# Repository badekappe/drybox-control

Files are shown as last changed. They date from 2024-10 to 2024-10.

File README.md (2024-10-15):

DryBox dryController
===

## Version 0.49.1

## Requirements
- Arduino IDE 1.8.2 or higher
- NewliquidCrystal (I2C)
- Adafruit SHT31 Library
- Adafruit BusIO (dependency of SHT31 library)

- 3D printing files and other parts list: https://www.printables.com/de/model/724722-filament-dry-box-heated-ventilated-arduino-control

## Changes with original
This is a detached fork from [werner_rh](https://github.com/werner-rh/drybox-control), in which I made the following changes:
- Replaced the DHT11 with SHT31. See also [this folder](./DHT31/)

## Description
Controller for an active heated and ventilated Filament DryBox. The Dryer contains a PTC Heater and a Fan for fresh dry air.

With one Heater, the box may barely reaches 55 degree. As max i reached 57 degree. I recommend not to go over 52-53 degree. If you need higher temperatures,
install a second heater. The MosFet switch will manage this. But you also need a stronger power supply (12V, 8-10A). A simple improvement
is insulating the walls inside. I used a car sun protect shield, with reflection and insulating. This improves the performance of
the box sigifignant. The warm up is much faster and also eaysier to to reach 55 degrees.

## Recommended drying temperatures
- PLA, PLA+                : 40-45 degree
- ABS, ABS+,  PETG         : 45-50 degree
- PVA,PVB, ASA, TPU, PMMA  : 50-55 degree

## Schematics
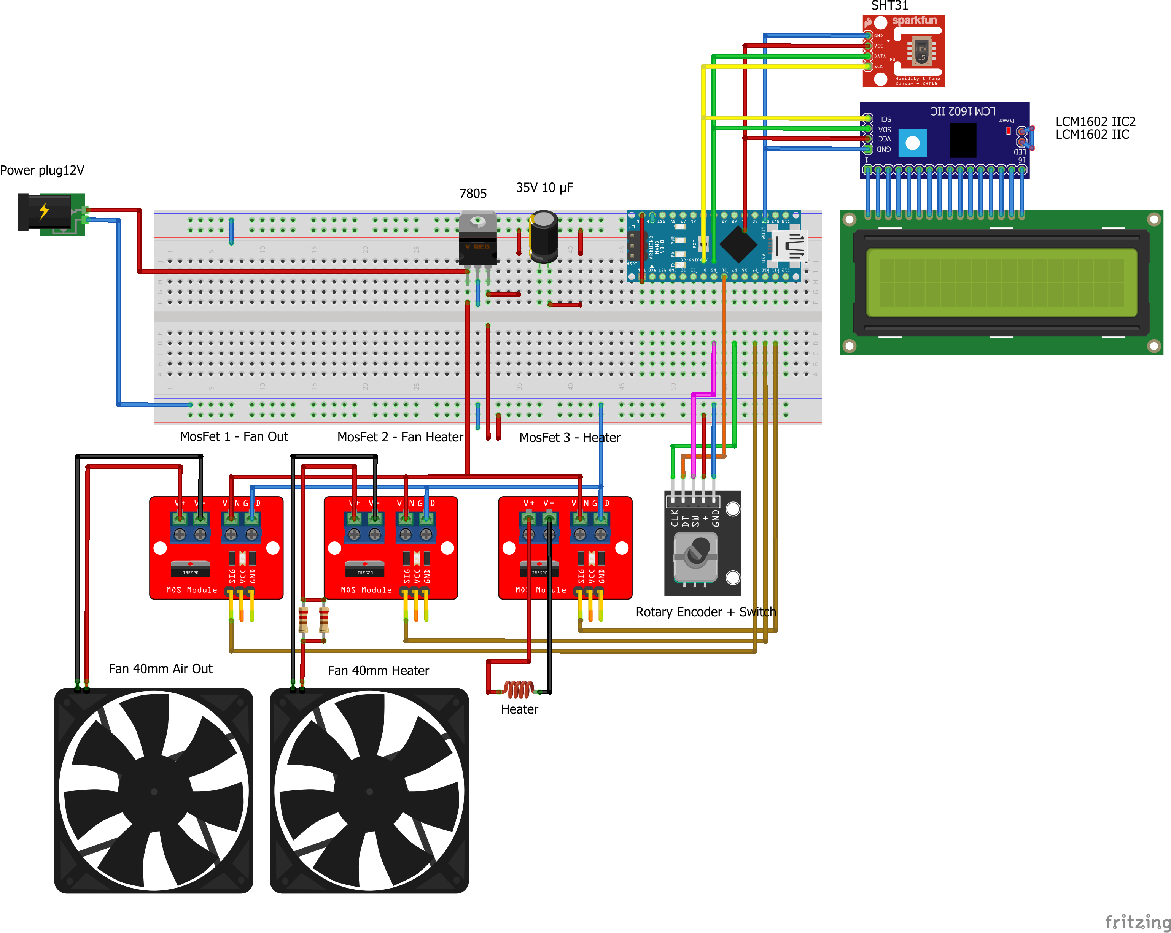
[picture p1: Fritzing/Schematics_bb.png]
On a breadboard


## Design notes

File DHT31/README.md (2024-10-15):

# DHT31
In this folder you'll find the files to print a mount for the DHT31 on a breakout board. You can glue or screw it in place, whichever you prefer.  
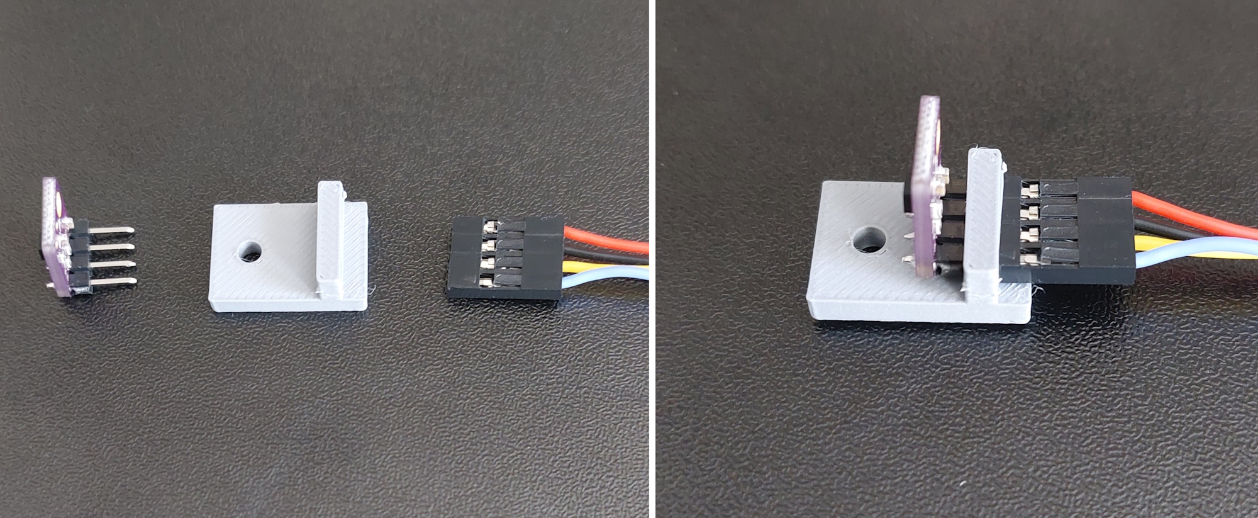
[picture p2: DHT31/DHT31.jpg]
mounting DHT31


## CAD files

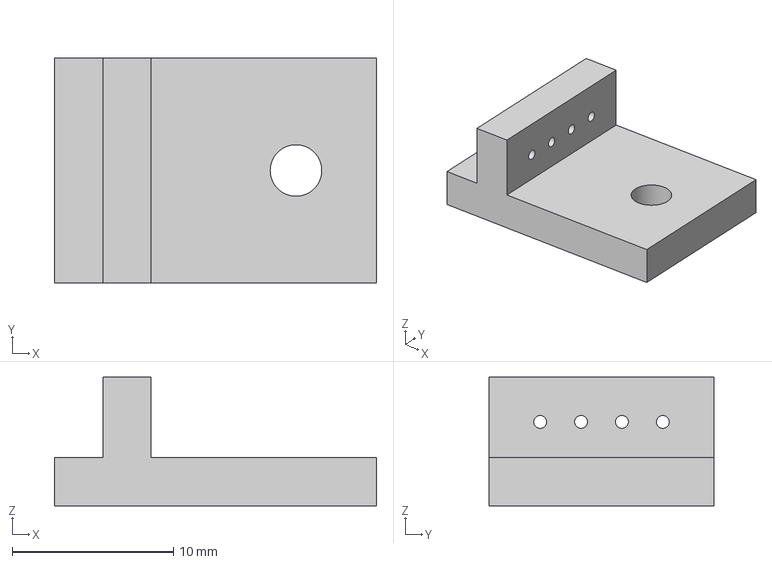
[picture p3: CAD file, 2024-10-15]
DHT31/DHT31-Mount.3mf
20.0 x 14.0 x 8.00 mm

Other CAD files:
DHT31/DHT31-Mount.stl

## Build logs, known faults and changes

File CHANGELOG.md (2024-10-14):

# Changelog
All notable changes for this project will be documented in this file

## [0.49.1] - 2024-10-14
### Changed
- Detached from original
- Replaced DHT11 with SHT31

## [0.49] - 2024-06-18
### Added
- Handling sensor error. If sensor fails during drying cycle, then drying process will be stopped and error message appear on the screen.
  
## [0.48] - 2024-05-08
### changed
- Refactoring Heating data. All values for heating power and heater fan speed are handled in an own class 
### Added
- Turbo mode for faster heating up in the lower ranges
- values for ventialtion time and final ventilation time
- replaced fix define for air exchange intervall with value in HeatingData

## [0.47] - 2024-05-05
### changed
- bugfix in function dryController(). Heater now is shut down after ventilation.
- bugfix in rampUpTable. Range over 50 degrees wasn't regarded and so powered to low.
### Added
- additional range over over 45 and 50 degrees. Now there are 6 ranges.
- display showing state of heater, heaterfan and ventilation during drying.
- refactored initializing power values for each tempeture range.
- adjust current values for low Hysteresis

## [0.46]
### Added
- last final ventilation after dry process is finished

## [0.45]
### Added
- first final version

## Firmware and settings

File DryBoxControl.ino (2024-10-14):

/***
 * Project: DryBox Control
 * File   : DryBoxControl.ino
 * Author : Werner Riemann 
 * Created: 18.10.2023
 * Board: Arduino Nano
 * 
 * Description: Controller for an active (heated) Filament DryBox.
 *              The Dryer contains a PTC Heater and a Fan for fresh dry air.
 *
 * Recommended drying temperatures:
 *    PLA, PLA+                : 40-45 degree
 *    ABS, ABS+,  PETG         : 45-50 degree
 *    PVA,PVB, ASA, TPU, PMMA  : 50-55 degree
 *
 *   Note: with one Heater, the box may barely reaches 55 degree. As max i reached 57 degree.
 *         I recommend not to go over 52-53 degree. If you need higher temperatures,
 *         install a second heater. The MosFet switch will manage this. But you
 *         also need a stronger power supply (12V, 8-10A).
 * 
 * Pins:
 * 
 * A4,A5  - I2C Display control and SHT31 (A4 - SDA, A5 - SCL)
 * 
 * 

 * D2     - not used
 * D1     - not used
 * D3     - not used
 * D4     - not used
 *
 * D5     - Rotary Encoder Switch
 * D6     - Rotary Encoder DT_pin                 Note: some encoder are different and you may have to change DT and CLK Pin.
 * D7     - Rotary Encoder CLK_pin                      Clockwise spin should increase all values.
 * D9     - Analog out PWM Fan Air exchange
 * D10    - Analog out PWM Fan Heating
 * D11    - Analog out PWM Heating
 * D12    - 
 * D13    - Digital out LEDPIN 13 (interne LED)
 * 
 *
 * --- Menu and functions ---
 * Main select: Temperature, Time, Start, Save, Version, Test functions (press Rotary to choose)
 * Temperature: change value by rotate, press to Rotary to exit
 * Time       : choose hour, minutes or Ret to exit. Press Rotary to enter value to change. Press Rotary again to exit value change.
 * Start      : press Rotary to start drying. Press Rotary during drying to pause or exit drying
 * Save       : press Rotary to save current setting for temperature and time to eeprom
 * Version    : shows the current version, press Rotary again to return to main
 * Test       : provides 3 functions for Heater, Heater Fan, Air Fan for Fresh air supply and exit Test.
 *              On exit Test menu, all values are set to zero and stops all modules.
 *
 *              This is useful to check all modules separately after assembling modules. Keep in mind to don't power
 *              up the heater without the fan for a longer time.
 */

#include <SPI.h>
#include <Wire.h>
#include <EEPROM.h>
#include <Arduino.h>
#include "Adafruit_SHT31.h"
#include "DryBoxControl.h"
#include "WRKeyStateDef.h"
#include "DryBoxDisplay.h"
#include "HeatingData.h"

volatile uint8_t B100HzToggle = 0;  // 100 Hertz Signal
uint8_t ui10MilliSekCount = 0;

int encoder_value = 500;
int last_encoder_value  = 500;
int EncSwitch = 5;
int DT_pin = 6;   //swap lines to change direction on the encoder
int CLK_pin = 7;  //swap lines to change direction on the encoder
int DT_pinstate;
int last_DT_pinstate;

int AirFanSpeed = 100;    // Extract Fan Speed in Percent
int HeatFanSpeed = 50;    // HeatFan Speed in Percent
int HeatingPower = 25;    // Heating Power in Percent

int testAirFanSpeed = 0;    // Extract Fan Speed in Percent for testing mode
int testHeatFanSpeed =0;    // HeatFan Speed in Percent for testing mode
int testHeatingPower =0;    // Heating Power in Percent for testing mode

// default values at startup, if nothing is stored in the eeprom
int DryTemperature = 35;    // Destination Dry Temperature in degree celsius
int DryTime_Hours = 1;      
int DryTime_Minutes = 30;
int curDryTime_Hours = 1;
int curDryTime_Minutes = 30;

//-- adjustable seetings for drying process, stored in HeatingData class
HeatingData heatingData;    // see HeatingData class


//-- State var for rotary encoder weitch  ----
uint8_t encoderBUTTON_State=0;

//-- Remember State on for Heater, Heater Fan and Ventilation
boolean StateHeaterOn = false;
boolean StateHeaterFanOn = false;
boolean StateVentilationOn = false;
boolean turboMode = false;

DryBoxDisplay display;
Adafruit_SHT31 sht31 = Adafruit_SHT31();


/***
 * Saves the current settings for temperature, drying hours and minutes
 */
void SaveSettings() {
  EEPROM.write(0, (uint8_t) 17);
  EEPROM.write(1, (uint8_t) DryTemperature);
  EEPROM.write(2, (uint8_t) DryTime_Hours);
  EEPROM.write(3, (uint8_t) DryTime_Minutes);
}


/***
 * Reads the last saved settings for temperature, drying hours and minutes
 */
void ReadSettings() {
  uint8_t isInit = EEPROM.read(0);

  if(isInit == 17) {
    DryTemperature = EEPROM.read(1);
    DryTime_Hours = EEPROM.read(2);
    DryTime_Minutes = EEPROM.read(3);
  }
}


// Interrupt is called once a millisecond, 
SIGNAL(TIMER0_COMPA_vect) 
{
  unsigned long currentMillis = millis();
  ui10MilliSekCount ++;

  if(ui10MilliSekCount >= 10 ) {
    ui10MilliSekCount = 0;
    B100HzToggle ^= 1;
  }

  ReadEncoder();  
}

void setup() {
  sht31.begin(0x44);
  
  // setup Rotary encoder
  pinMode (DT_pin, INPUT);
  pinMode (CLK_pin, INPUT);
  digitalWrite(DT_pin, HIGH);
  digitalWrite(CLK_pin, HIGH);

  // setup Heating and air 
  pinMode(FANAIR_PIN, OUTPUT);  
  analogWrite(FANAIR_PIN, 0);            // PWM Extrcat Fan off
  pinMode(FANHEATING_PIN, OUTPUT);  
  analogWrite(FANHEATING_PIN, 0);        // PWM Heating Fan  off
  pinMode(HEATING_PIN, OUTPUT);
  analogWrite(HEATING_PIN, 0);           // PWM Heating off  

  ReadSettings();

  // Reads the initial state of DT
  last_DT_pinstate = digitalRead(DT_pin);

  display.Setup();
  display.SetVersion(APP_VERSION);
  display.ScreenOut(SCR_WELCOME);

  // Timer setup --------------------------
  // Timer0 is already used for millis() - we'll just interrupt somewhere
  // in the middle and call the "Compare A" function below
  OCR0A = 0xAF;
  TIMSK0 |= _BV(OCIE0A);    

}

void ReadEncoder() {
    DT_pinstate = digitalRead(DT_pin);
    if (DT_pinstate != last_DT_pinstate) { //did DT changed state?
      if (digitalRead(CLK_pin) == DT_pinstate) { // if DT changed state, check CLK
        encoder_value--; // rotation is counter-clockwise, decrement the value
      }else{
        encoder_value++; // rotation is clockwise, increment the value
      }
    last_DT_pinstate = DT_pinstate; //save the last state of DT
    }
}


/***
 * EncoderValueChange - increments or decrements the value of given var depending
 * from the direction the rotary encoder is moved. The Value of var is kept in range
 * of rangeMin and rangeMax.
 * 
 * param int * valToModify : pointer of var to modify
 * param int rangeMin: minimum value 
 * param int rangeMax: maximum value
*/
void EncoderValueChange(int * valToModify, int rangeMin, int rangeMax) {
    int aktValue = * valToModify;

    if(last_encoder_value != encoder_value)
    {

      if(encoder_value > last_encoder_value +1)
      {
        last_encoder_value = encoder_value;
        if(aktValue < rangeMax)
          aktValue ++;
      }
      
      if(encoder_value +1  < last_encoder_value )
      {
        last_encoder_value = encoder_value;
        if(aktValue > rangeMin)
        aktValue --;
      }
    }

    * valToModify = aktValue;
}


boolean IsPWMStateOn(int pwmValue) {
  if(pwmValue > 0)
    return true;
  else  
    return false;
}

void SetPWMRate(uint8_t pin, int ratePercent)
{
  int PWMVal = 255 * ratePercent / 100;
  analogWrite(pin,PWMVal);

  // check which Pin (heater, heater fan or ventilation) and store the state on or off
  switch (pin) {
  case FANAIR_PIN: StateVentilationOn = IsPWMStateOn(PWMVal);
  break;
  case FANHEATING_PIN: StateHeaterFanOn = IsPWMStateOn(PWMVal);
  break;
  case HEATING_PIN: StateHeaterOn = IsPWMStateOn(PWMVal);
  break;
  }
}


// Main loop -----------------------------------------------------------
void loop() {
  static uint8_t AppState=0;
  static uint8_t StateTrigger = 0;
  uint8_t aktStateTrigger;
  static int aktModeNo = 1;
  static int aktTestModeNo = 1;
  static int aktTimeEdMode = 1;  // 1= edit hour, 2= minutes, 3= exit edit
  static int aktBreakModNo = 1;

  static uint8_t ui100HzSecCounter=0;   // counter for a second
  static uint8_t ui100HzSensorTimer=200;  // read SHT31 sensor every 2 seconds
  static int runMinuteTimer = 6000;
  static int airExChgEndCounter = 2000;
  static float humidity = 0.0;
  static float temperature = 0.0;
  
  int oldHeatFanSpeed=0;
  int oldAirFanSpeed=0;
  int oldHeatingPower=0;
  int oldModeNo=0;
  int oldTestModeNo=0;
  int oldTimeEdMode=0;  
  int oldDryTemperature=0;
  int oldTimeVal=0;
  int oldBreakModNo = 1;
  
  char szBuf[8];

  aktStateTrigger = B100HzToggle;

  // Processing State-Machine. ----------------------------------------------------------
  // The state machine is triggered on every Change of flank of the timer toogle.
  // This happens 100 times in a second.

  if(aktStateTrigger != StateTrigger) {
    StateTrigger = aktStateTrigger;

    CheckKeyState(&encoderBUTTON_State, EncSwitch);

    // No need to read sensor every loop
    if(ui100HzSensorTimer > 0) {
      ui100HzSensorTimer--;
    } else {
      ui100HzSensorTimer = 1000;
      humidity = sht31.readHumidity();
      temperature = sht31.readTemperature();
      // Check for NaN values
      if (isnan(humidity) || isnan(temperature)) {
        // Stop the drying process if NaN values are detected
        dryController(DST_TEARDOWN, temperature);
        display.ScreenOut(SCR_ERROR); 
        display.PrintError("SHT Sensor Error"); // Display error message
  
        AppState = AST_IDLE; // Transition to a safe state
      }
      if(AppState == AST_MODE_SELECT || AppState == AST_RUNDRYING || AppState == AST_TESTMODE) {
        display.PrintTHValue(temperature, humidity);
      }
    }

    // App-State-Machine processing and step through
    switch(AppState) {

      case AST_IDLE:
          
        if(encoderBUTTON_State == 1 )
        {
        AppState = AST_PREPARE_SELECT;
        }
        break;

      case AST_PREPARE_SELECT:
        display.ScreenOut(SCR_MENUBASE);
        display.updateModSelect(aktModeNo);
        if(aktModeNo == 1)
          display.PrintDestTemp(DryTemperature, 6);
        if(aktModeNo == 2)
          display.PrintDestTime(DryTime_Hours, DryTime_Minutes, 6);
        AppState = AST_MODE_SELECT;      
        break;

      case AST_MODE_SELECT:
        oldModeNo = aktModeNo;    
        EncoderValueChange(&aktModeNo, 1, 6);     
        if(oldModeNo != aktModeNo)  // there is a change
        {
          display.updateModSelect(aktModeNo);
          if(aktModeNo == 1)
            display.PrintDestTemp(DryTemperature, 6);
          if(aktModeNo == 2)
            display.PrintDestTime(DryTime_Hours, DryTime_Minutes, 6);
        }         

        if(encoderBUTTON_State == 1 && aktModeNo == SELMOD_DRYTEMP)  // encoder switch pressed, set temperature
        {
          display.ScreenOut(SCR_SETTEMP);
          display.PrintDestTemp(DryTemperature, 0);
          display.CursorPos(1, 1);
          display.CursorOn();
          AppState = AST_SET_DRYTEMP;
        }

        if(encoderBUTTON_State == 1 && aktModeNo == SELMOD_DRYTIME)  // encoder switch pressed, set time
        {
          display.ScreenOut(SCR_SETTIME);
          display.PrintDestTime(DryTime_Hours, DryTime_Minutes, 0);
          display.CursorPos(0, 1);
          display.BlinkOn();          
          aktTimeEdMode = 1;
          AppState = AST_SET_DRYTIME;
        }

        if(encoderBUTTON_State == 1 && aktModeNo == SELMOD_DRYSTART)  // encoder switch pressed, start drying
        {
          display.ScreenOut(SCR_RUNNING);
          display.PrintHFVState(StateHeaterOn, StateHeaterFanOn, StateVentilationOn, turboMode);
          display.PrintDestTemp(DryTemperature, 0);
          display.PrintDestTime(DryTime_Hours, DryTime_Minutes, 5);
          curDryTime_Hours = DryTime_Hours;
          curDryTime_Minutes = DryTime_Minutes;
          runMinuteTimer = 6000;
          dryController(DST_STARTUP, temperature);
          AppState = AST_RUNDRYING;
        }

        // save actual settings
        if(encoderBUTTON_State == 1 && aktModeNo == SELMOD_SAVE)
        {
          display.ScreenOut(SCR_SAVED);
          SaveSettings();
          AppState = AST_IDLE;
        }

        if(encoderBUTTON_State == 1 && aktModeNo == SELMOD_VERSION)
        {
          display.ScreenOut(SCR_WELCOME);
          AppState = AST_IDLE;
        }

        if(encoderBUTTON_State == 1 && aktModeNo == SELMOD_TESTING)  // encoder switch pressed, start testing mode
        {
          display.ScreenOut(SCR_TESTING);
          aktTestModeNo = 1;
          display.updateTestModSelect(aktTestModeNo);
          testAirFanSpeed = 0;    
          testHeatFanSpeed =0;    
          testHeatingPower =0;  
          AppState = AST_TESTMODE;
        }
        break;

      case AST_SET_DRYTEMP:
        oldDryTemperature = DryTemperature;
        // with one Heater, 57° is maximum. For more temperature, a second Heater 
        // and a bigger power supply is necessary.
        EncoderValueChange(&DryTemperature, 1, 55);   
        if(oldDryTemperature != DryTemperature)
        {
          display.PrintDestTemp(DryTemperature, 0);    
          display.CursorPos(1, 1);      
        }

        if(encoderBUTTON_State == 1)
        {
          display.CursorOff();
          AppState = AST_PREPARE_SELECT;
        }
        break;

      case AST_SET_DRYTIME: // select hour, minutes or Return
        oldTimeEdMode = aktTimeEdMode;
        EncoderValueChange(&aktTimeEdMode, 1, 3);
        if(oldTimeEdMode != aktTimeEdMode)
        {
          display.SetEdTimeCursorPos(aktTimeEdMode);
          display.BlinkOn();        
        }

        if(encoderBUTTON_State == 1 && aktTimeEdMode == 1) // change hours
        {
          display.BlinkOff();
          display.CursorOn();
          AppState = AST_ED_DRYHOUR;
        } 

        if(encoderBUTTON_State == 1 && aktTimeEdMode == 2) // change minutes
        {
          display.BlinkOff();
          display.CursorOn();
          AppState = AST_ED_DRYMINUTE;
        }                       

        if(encoderBUTTON_State == 1 && aktTimeEdMode == 3)
        {
          display.BlinkOff();
          AppState = AST_PREPARE_SELECT;
        }
        break;

      case AST_ED_DRYHOUR:
        oldTimeVal = DryTime_Hours;
        EncoderValueChange(&DryTime_Hours, 0, 9);
        if(oldTimeVal != DryTime_Hours)
        {
          display.PrintDestTime(DryTime_Hours, DryTime_Minutes, 0);
          display.SetEdTimeCursorPos(aktTimeEdMode);         
        }

        if(encoderBUTTON_State == 1) // return to Edit select
        {
          display.SetEdTimeCursorPos(aktTimeEdMode);
          display.CursorOff();
          display.BlinkOn();
          AppState = AST_SET_DRYTIME;
        }
        break;

      case AST_ED_DRYMINUTE:
        oldTimeVal = DryTime_Minutes;
        EncoderValueChange(&DryTime_Minutes, 0, 59);
        if(oldTimeVal != DryTime_Minutes)
        {
          display.PrintDestTime(DryTime_Hours, DryTime_Minutes, 0);
          display.SetEdTimeCursorPos(aktTimeEdMode);         
        }

        if(encoderBUTTON_State == 1) // return to Edit select
        {
          display.SetEdTimeCursorPos(aktTimeEdMode);
          display.CursorOff();
          display.BlinkOn();
          AppState = AST_SET_DRYTIME;
        }      
        break;        

      case AST_RUNDRYING:
        // Timer check and display -------------------------------
        // The active state is called 100 times per second. So 6000 equals one minute
        if(runMinuteTimer > 0) {
          runMinuteTimer--;
        }
        else {
          runMinuteTimer = 6000;
          if(curDryTime_Minutes > 0) {
            curDryTime_Minutes--;
            display.PrintHFVState(StateHeaterOn, StateHeaterFanOn, StateVentilationOn, turboMode);
            display.PrintDestTime(curDryTime_Hours, curDryTime_Minutes, 5);
               
          } else {
            if(curDryTime_Hours > 0) {
              curDryTime_Hours--;
              curDryTime_Minutes = 59;
              display.PrintDestTime(curDryTime_Hours, curDryTime_Minutes, 5);
            } else {
              // drying ready
              dryController(DST_TEARDOWN, temperature);
              display.PrintHFVState(StateHeaterOn, StateHeaterFanOn, StateVentilationOn, turboMode);
              AppState = AST_ENDVENTILATION;
              //final fresh air ventilation after drying
              airExChgEndCounter = (int) heatingData.finalAirExtractionTime * 100;  // fresh air for defined amount of seconds
              SetPWMRate(FANAIR_PIN, 80);              
              display.PrintHFVState(StateHeaterOn, StateHeaterFanOn, StateVentilationOn, turboMode);
            }
          }
        }

        // Heating control ------------------------------------
        if(AppState == AST_RUNDRYING) {// only while AST_RUNDRYING is active, call dryController
          dryController(0, temperature);
          display.PrintHFVState(StateHeaterOn, StateHeaterFanOn, StateVentilationOn, turboMode);
        }

        if(encoderBUTTON_State == 1)
        {
          AppState = AST_RUNPAUSE;
          dryController(DST_BREAK, temperature);
          display.ScreenOut(SCR_RUNBREAK);
          display.CursorPos(0, 1);          
          display.BlinkOn();
          aktBreakModNo=1;
        }
        break;        

      case AST_ENDVENTILATION:
        if(airExChgEndCounter > 0) {
          airExChgEndCounter--;
        } 
        else {
          SetPWMRate(FANAIR_PIN, 0);
          AppState = AST_PREPARE_SELECT;
        }
        break;

      case AST_RUNPAUSE:
        oldBreakModNo = aktBreakModNo;
        EncoderValueChange(&aktBreakModNo, 1, 2);
        if(oldBreakModNo != aktBreakModNo) {
          display.SetBreakCursorPos(aktBreakModNo);
        }

        if(encoderBUTTON_State == 1 && aktBreakModNo == 1) // continue
        {
          display.BlinkOff();
          dryController(DST_CONTINUE, temperature);
          dryController(0, temperature);
          AppState = AST_RUNDRYING;
          display.ScreenOut(SCR_RUNNING);
          display.PrintHFVState(StateHeaterOn, StateHeaterFanOn, StateVentilationOn, turboMode);
          display.PrintDestTemp(DryTemperature, 0);
          display.PrintDestTime(curDryTime_Hours, curDryTime_Minutes, 5);
        }    

        if(encoderBUTTON_State == 1 && aktBreakModNo == 2) // stop
        {
          display.BlinkOff();
          dryController(DST_TEARDOWN, temperature);
          AppState = AST_PREPARE_SELECT;           
        }      
        break;
      
      case AST_TESTMODE:
        oldTestModeNo = aktTestModeNo;
        EncoderValueChange(&aktTestModeNo, 1, 4);
        if(oldTestModeNo != aktTestModeNo) {
          display.updateTestModSelect(aktTestModeNo);
        if(aktTestModeNo == 2)
          display.PrintPercentValue(testHeatFanSpeed);
        if(aktTestModeNo == 3)
          display.PrintPercentValue(testHeatingPower);
        if(aktTestModeNo == 4)
          display.PrintPercentValue(testAirFanSpeed);
        }    

        if(encoderBUTTON_State == 1 && aktTestModeNo == 1) { // exit testing
          SetPWMRate(HEATING_PIN, 0);
          SetPWMRate(FANHEATING_PIN, 0);
          SetPWMRate(FANAIR_PIN, 0);

          AppState = AST_PREPARE_SELECT;
        }

        if(encoderBUTTON_State == 1 && aktTestModeNo == 2) { // set test Fan speed
          display.PrintPercentValue(testHeatFanSpeed);
          display.CursorPos(6, 1);
          display.CursorOn();          
          AppState = AST_FAN_CONTROL;
        }

        if(encoderBUTTON_State == 1 && aktTestModeNo == 3) { // set test Heat power
          display.PrintPercentValue(testHeatingPower);
          display.CursorPos(6, 1);
          display.CursorOn();          
          AppState = AST_HEAT_CONTROL;
        }

        if(encoderBUTTON_State == 1 && aktTestModeNo == 4) { // set test Air Fan speed
          display.PrintPercentValue(testAirFanSpeed);
          display.CursorPos(6, 1);
          display.CursorOn();          
          AppState = AST_AIR_CONTROL;
        }        
        break;
      
      // Fan Speed, on exit switch off Fan
      case AST_FAN_CONTROL:
        oldHeatFanSpeed = testHeatFanSpeed;
        EncoderValueChange(&testHeatFanSpeed, 0, 99);
        if(oldHeatFanSpeed != testHeatFanSpeed) {
          display.PrintPercentValue(testHeatFanSpeed);
          SetPWMRate(FANHEATING_PIN, testHeatFanSpeed);
        }

        if(encoderBUTTON_State == 1 )
        { 
        display.CursorOff();
        display.updateTestModSelect(aktTestModeNo);
        display.PrintPercentValue(testHeatFanSpeed);
        AppState = AST_TESTMODE;
        }
        break;

      case AST_AIR_CONTROL:
        oldAirFanSpeed = testAirFanSpeed;
        EncoderValueChange(&testAirFanSpeed, 0, 99);
        if(oldAirFanSpeed != testAirFanSpeed) {
          display.PrintPercentValue(testAirFanSpeed);
          SetPWMRate(FANAIR_PIN, testAirFanSpeed);
        }

        if(encoderBUTTON_State == 1 )
        {
        display.CursorOff();
        display.updateTestModSelect(aktTestModeNo);
        display.PrintPercentValue(testAirFanSpeed);
        AppState = AST_TESTMODE;
        }
        break;

      case AST_HEAT_CONTROL:
        oldHeatingPower = testHeatingPower;
        EncoderValueChange(&testHeatingPower, 0, 99);
        if(oldHeatingPower != testHeatingPower) {
          display.PrintPercentValue(testHeatingPower);
          SetPWMRate(HEATING_PIN, testHeatingPower);
        }

        if(encoderBUTTON_State == 1 )
        {
        display.CursorOff();
        display.updateTestModSelect(aktTestModeNo);
        display.PrintPercentValue(testHeatingPower);
        AppState = AST_TESTMODE;
        }
        break;        
    }

  }

}

// --- functions for temperature control ------------------
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

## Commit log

2024-10-14 Replaced DHT11 with SHT31
    [Schematics.fzz]
2024-10-15 DHT31 3D-printer files
    [DHT31-Mount.3mf, DHT31-Mount.stl]
